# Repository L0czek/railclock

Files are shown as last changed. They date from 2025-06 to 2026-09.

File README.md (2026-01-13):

# ESP32 Mainboard (Railclock-derived)

> A general-purpose ESP32-C6 module mainboard originally created for the Railclock project and redesigned as a generic controller and motor-power board.

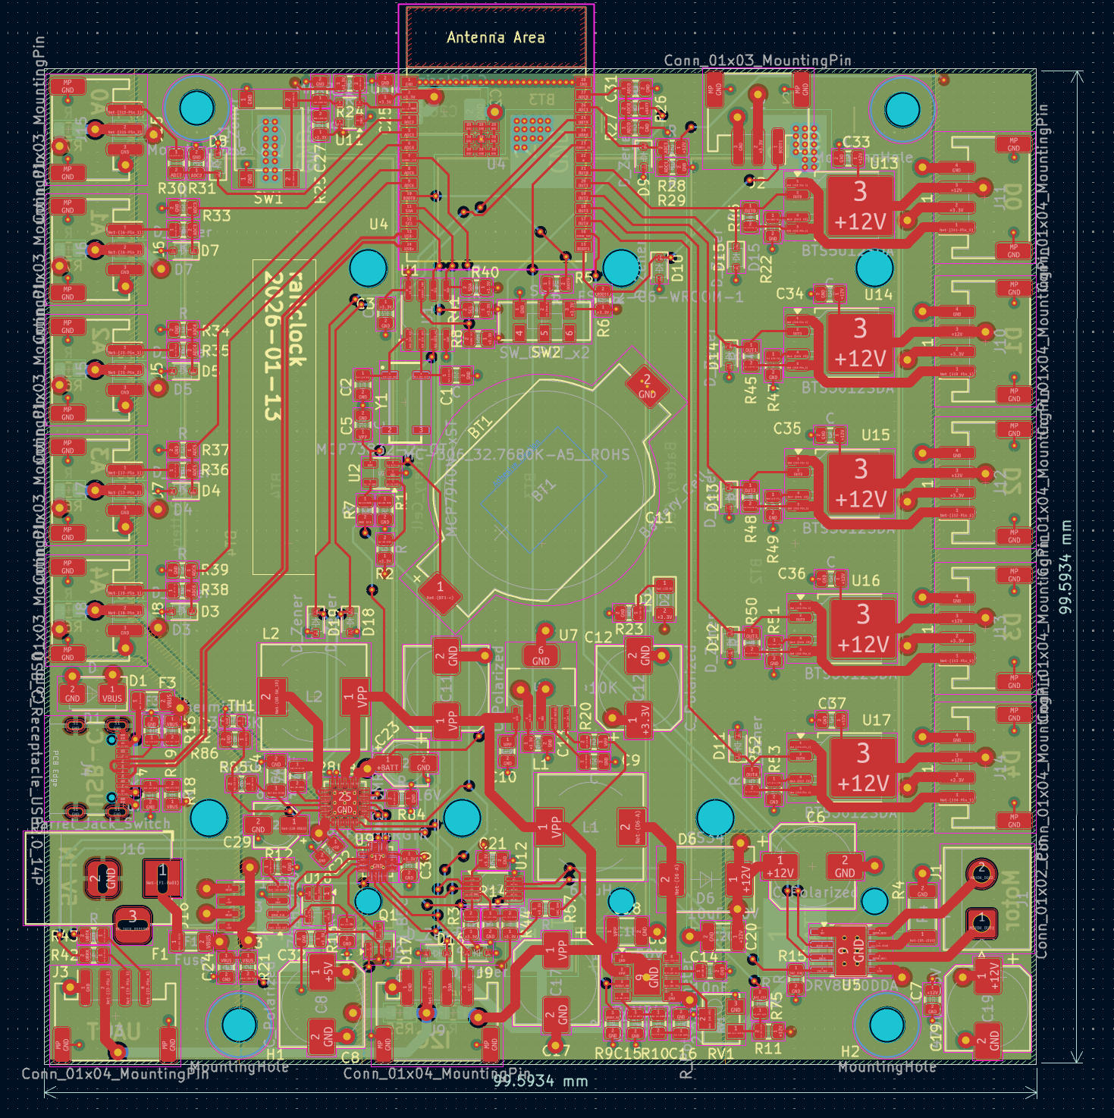
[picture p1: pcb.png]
PCB top view


This PCB exposes 11 GPIOs via JST connectors for sensors and actuators. It can run without an external 5V supply by using an on-board battery charger and a boost converter to create a 12V rail for motors and higher-power peripherals.

## Key Features

- 11 accessible GPIOs on JST connectors (5 ADC-capable ports on the left, 5 digital/drive outputs on the right).
- Left side ports: ADC-capable pins and a selectable 5V supply (powered by on-board 5V regulator/charger when available).
- Right side ports: digitally-driven output stage able to source up to 12V and ~800 mA (per port design limits depend on load and thermal conditions).
- On-board power management:
  - BQ24296M battery charger to accept battery power and produce the 5V line when no external USB is present.
  - PAM2421 boost converter to generate the 12V rail from the battery/5V bus.
- Motor driver: DRV8870 used to drive DC motors from the 12V rail.
- RTC clock MCP7940n with separate battery.

## Hardware Overview

- Connectors:
  - Left JST ports: ADC-capable pins. Expect up to 5V on these when the 5V supply is enabled — do not exceed 5V on ADC inputs.
  - Right JST ports: digital outputs with high-side/outstage to provide up to 12V for actuators.
- Power flow:
  - Primary charge/power management by the BQ24296M allows operation from a Li-ion battery without external 5V.
  - The PAM2421 boost converter takes the available rail and creates the 12V bus used by the outputs and motor driver.
- Motor driver:
  - DRV8870 drives DC motors using the 12V rail; follow the datasheet for current-limiting and heat-sinking requirements.

## Firmware

Firmware for this board is written in Rust and maintained in a separate repository: https://github.com/L0czek/esp32-mainboard

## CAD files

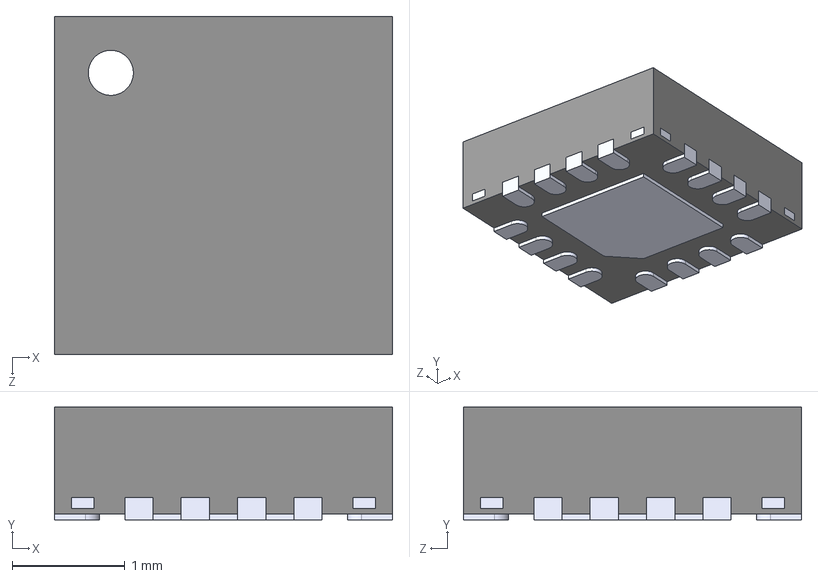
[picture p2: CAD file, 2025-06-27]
th/PCF8574RGTR.step
3.00 x 1.00 x 3.00 mm

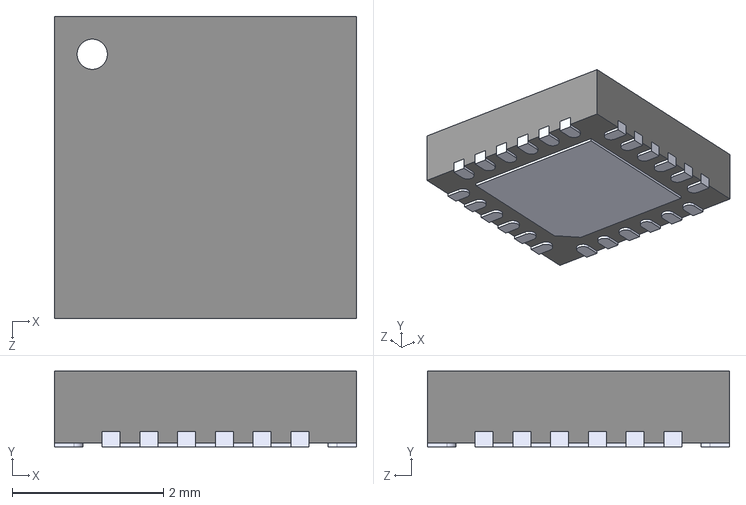
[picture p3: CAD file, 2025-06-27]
th/BQ24296MRGET.step
4.00 x 1.00 x 4.00 mm

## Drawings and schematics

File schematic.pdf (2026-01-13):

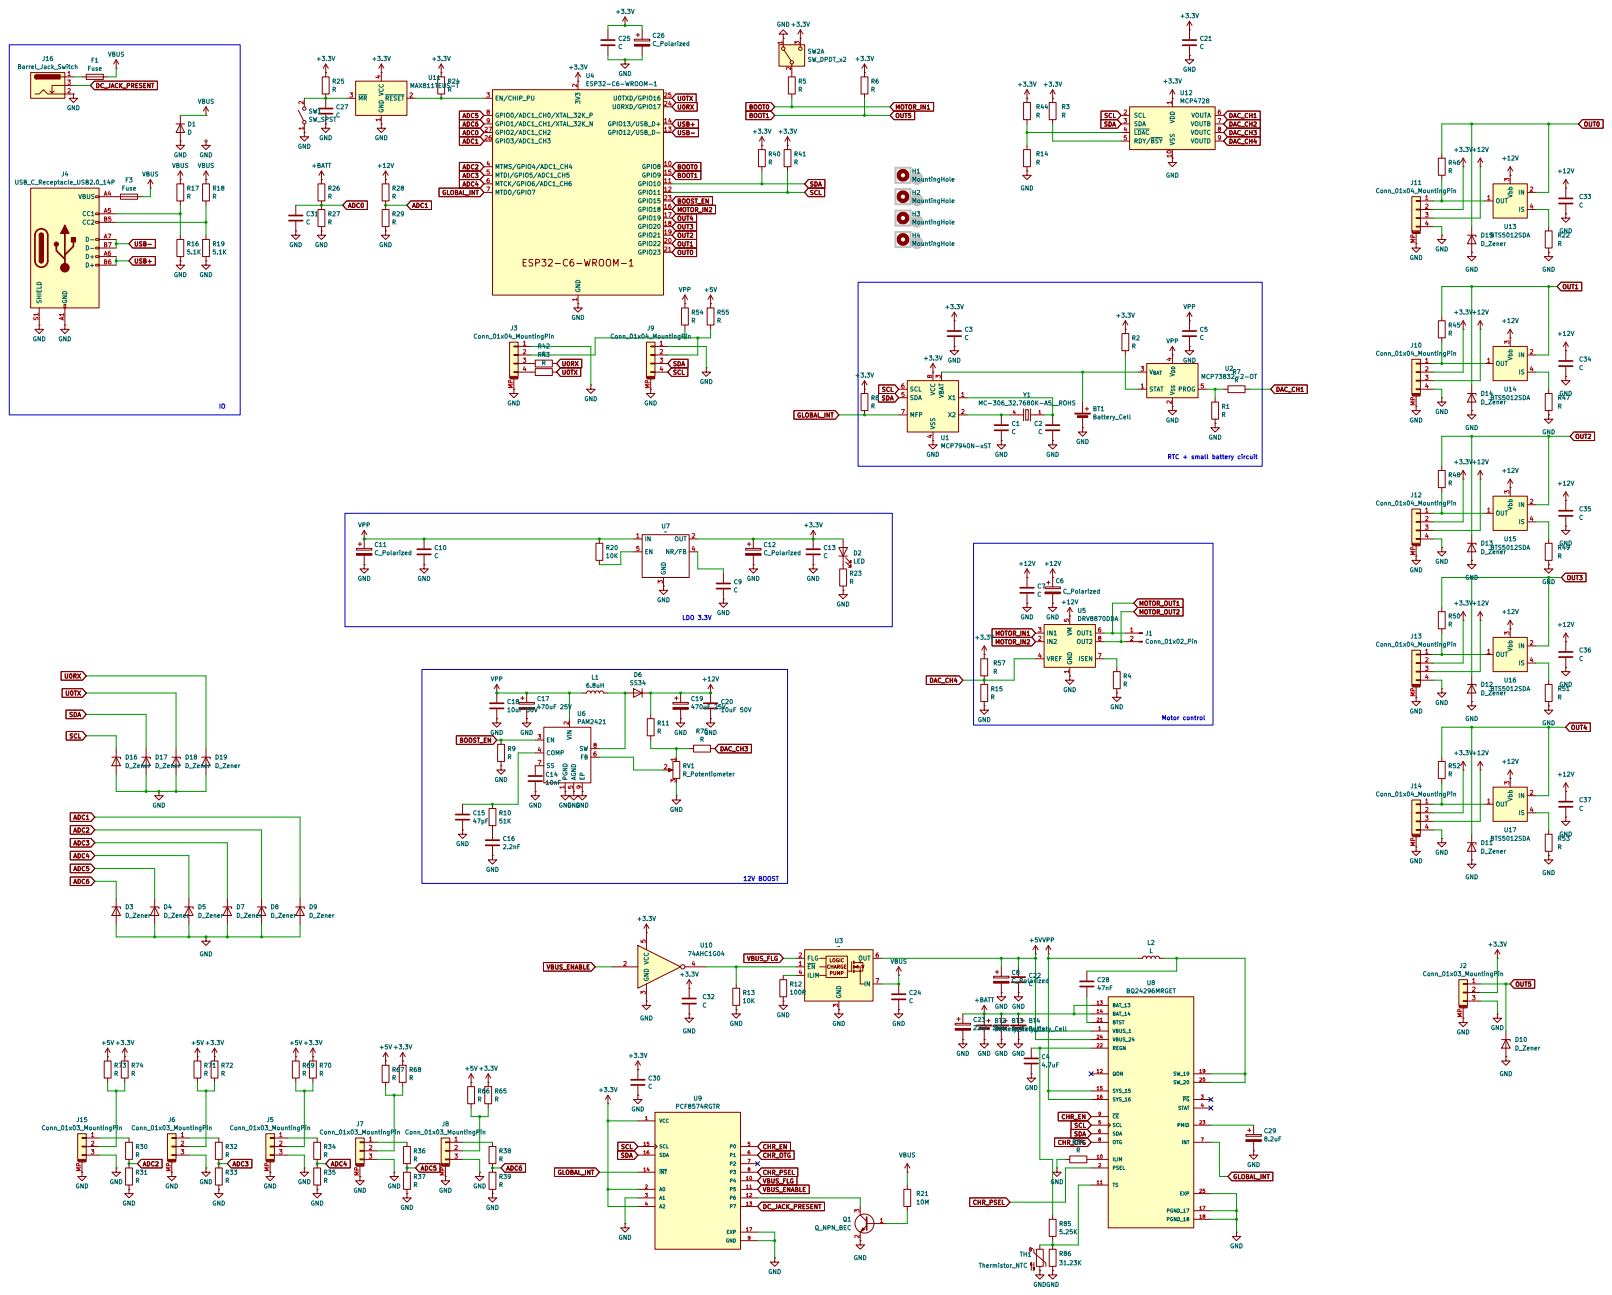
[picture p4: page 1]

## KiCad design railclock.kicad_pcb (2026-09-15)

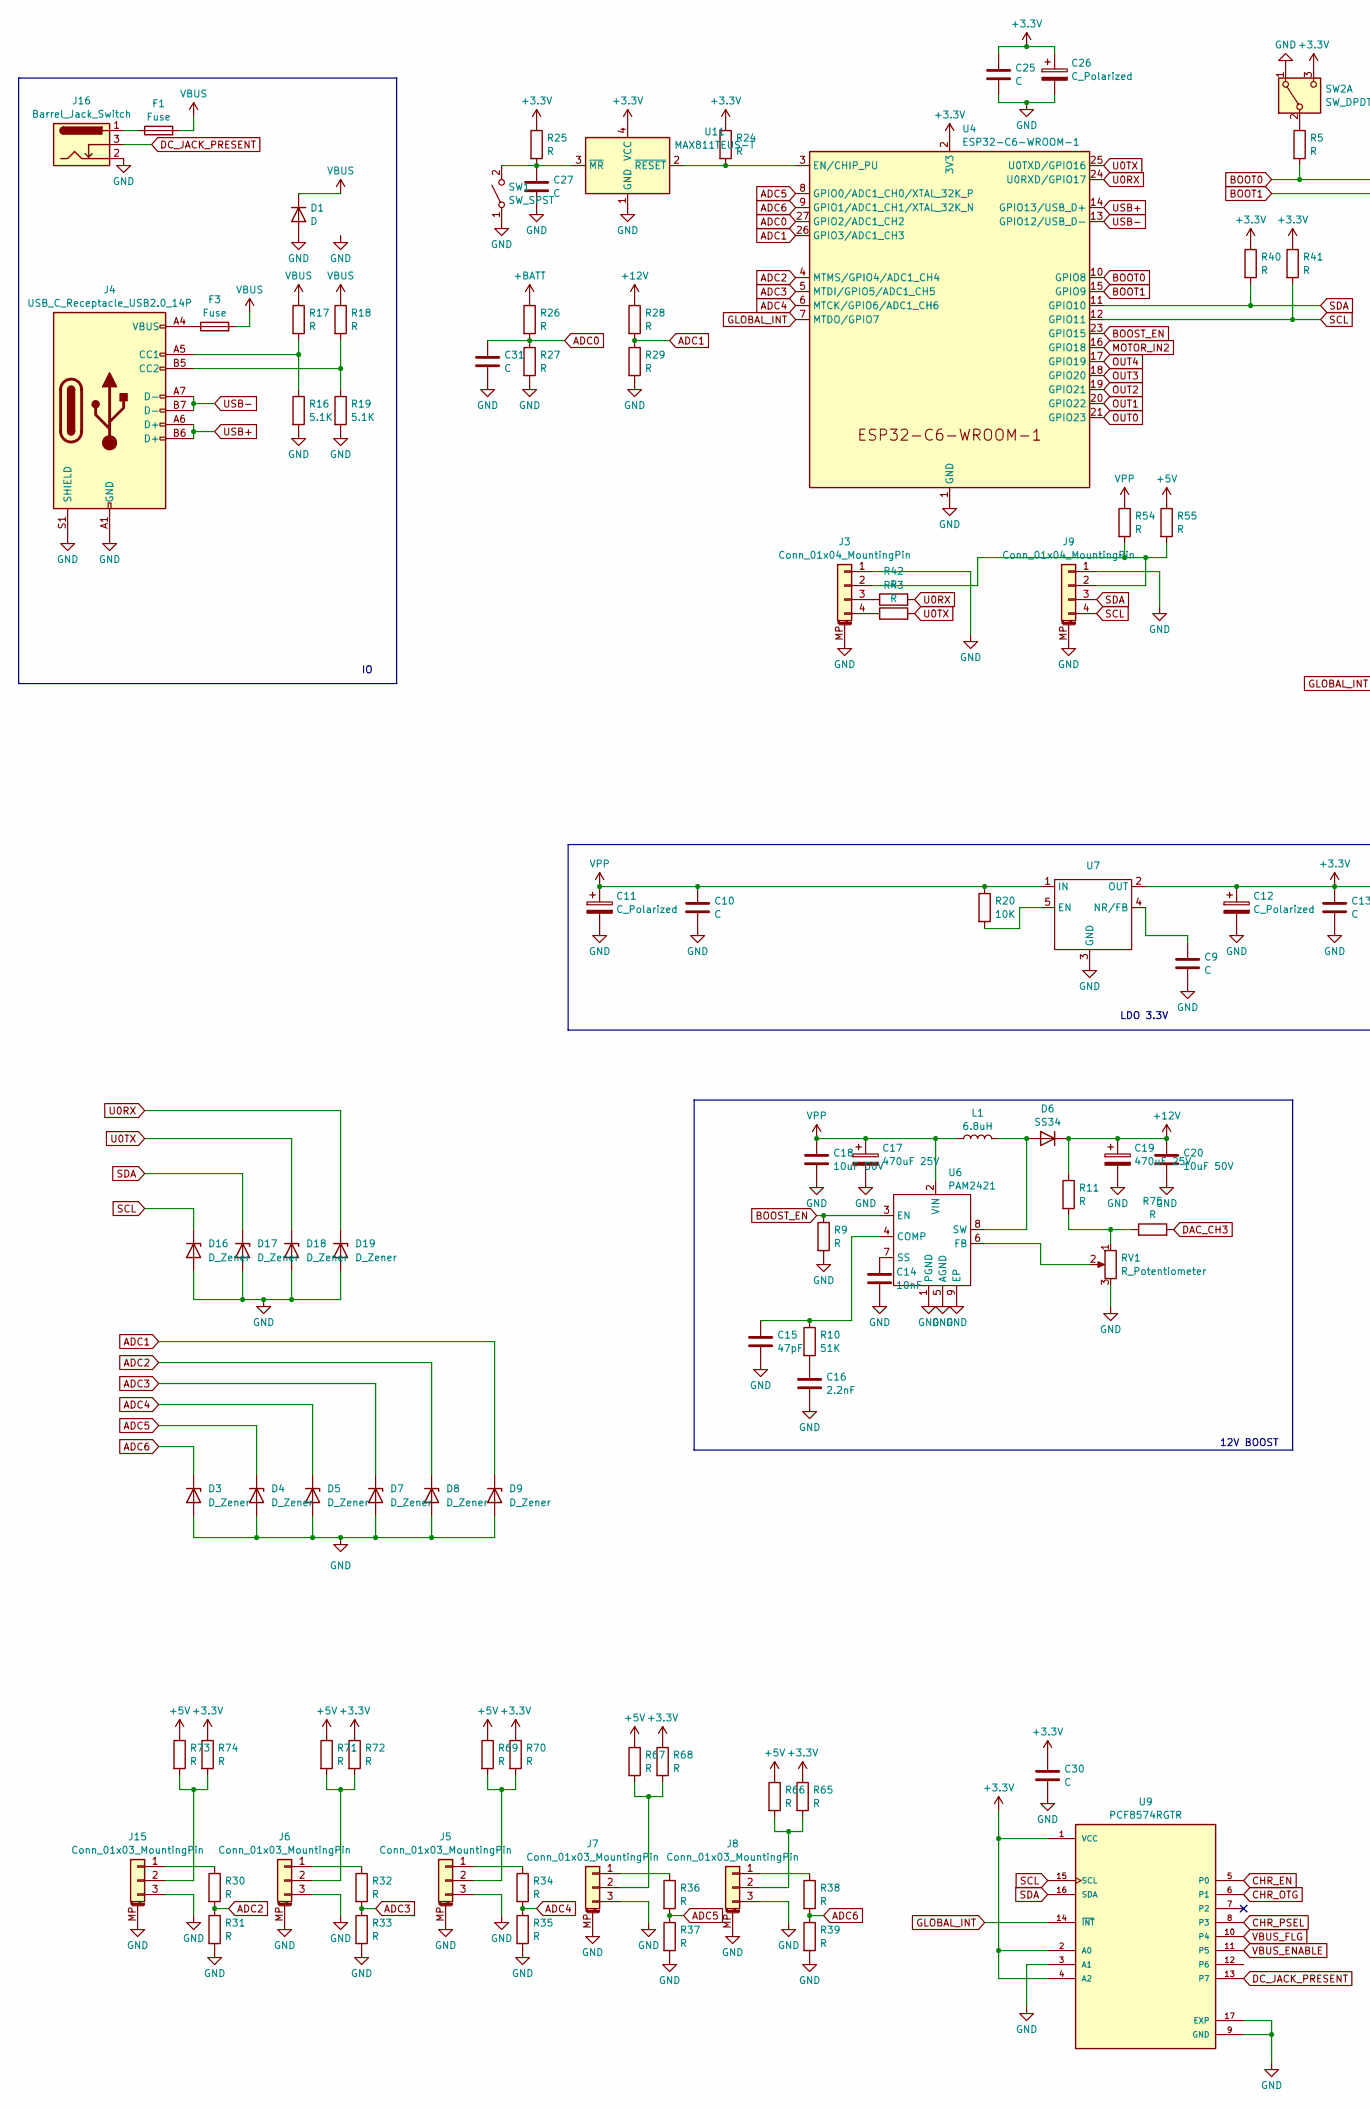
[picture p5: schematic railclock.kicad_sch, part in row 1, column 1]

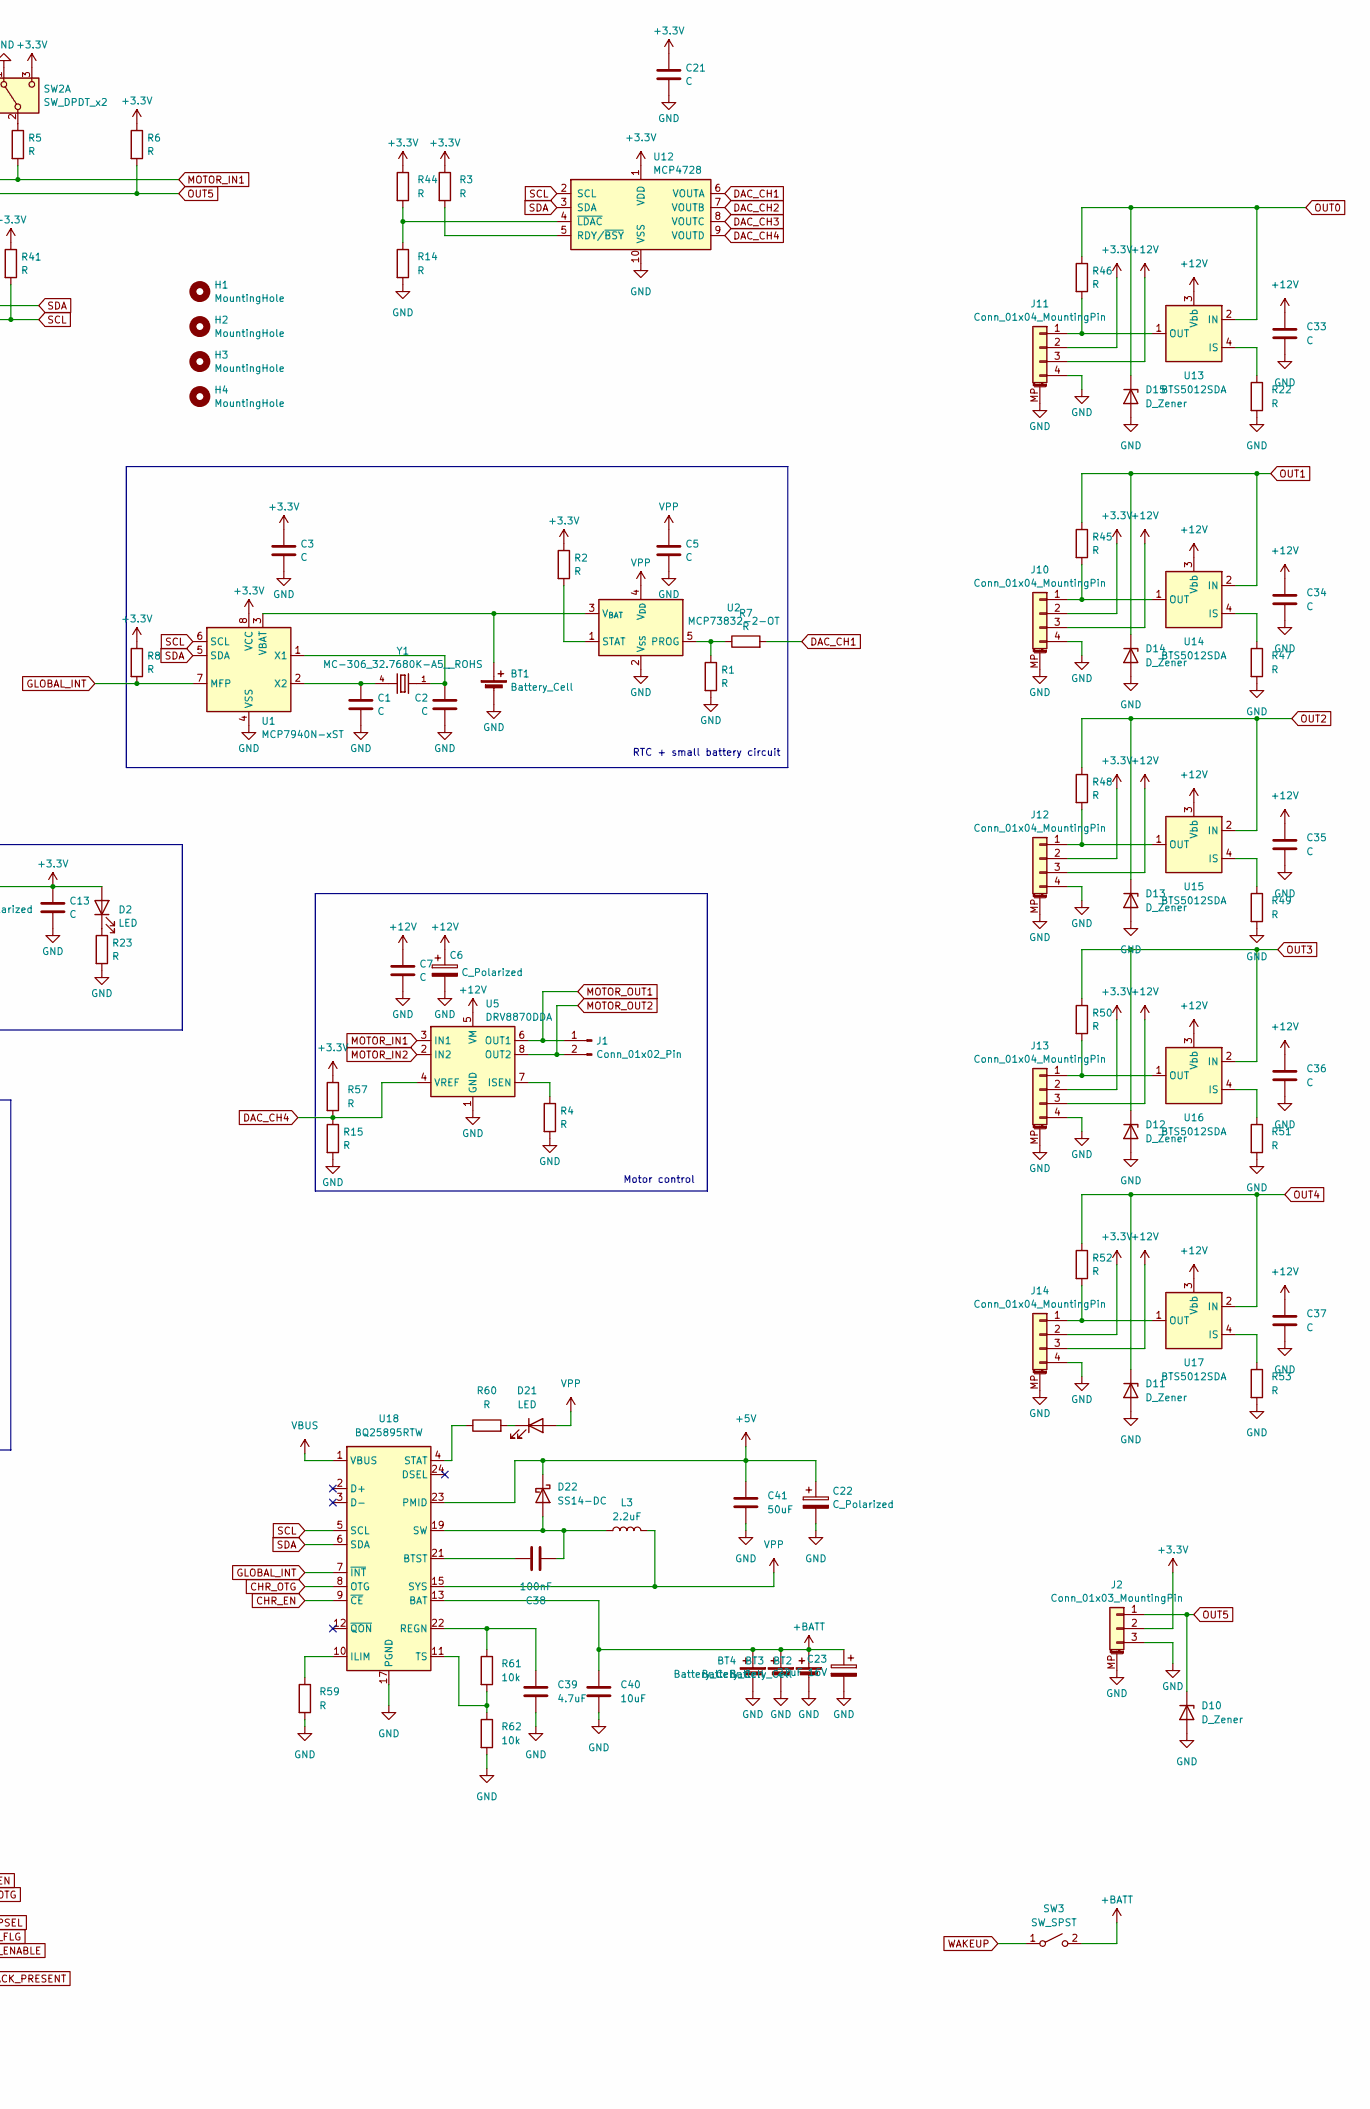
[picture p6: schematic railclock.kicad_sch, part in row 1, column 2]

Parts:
BT1: Battery_Cell; BatteryHolder_Renata_SMTU2032-LF_1x2032
BT2, BT3, BT4: Battery_Cell; BatteryHolder_Keystone_1042_1x18650
C1, C2, C3, C5, C7, C9, C10, C13, C21, C25, C27, C30, C31, C33, C34, C35, C36, C37: C; C_0805_2012Metric
C6, C11, C12, C22: C_Polarized; CP_Elec_8x10
C14: 10nF; C_0805_2012Metric
C15: 47pF; C_0805_2012Metric
C16: 2.2nF; C_0805_2012Metric
C17, C19: 470uF 25V; CP_Elec_8x10
C18, C20: 10uF 50V; C_1210_3225Metric
C23: 22uF 16V; CP_Elec_4x5.3
C26: C_Polarized; CP_EIA-7343-31_Kemet-D
C38: 100nF; C_0805_2012Metric
C39: 4.7uF; C_0805_2012Metric
C40: 10uF; C_0805_2012Metric
C41: 50uF; C_0805_2012Metric
D1: D; D_SMA
D2: LED; LED_1206_3216Metric
D3, D4, D5, D7, D8, D9, D10, D11, D12, D13, D14, D15, D16, D17, D18, D19: D_Zener; D_SOD-323
D6: SS34; D_SMC
D21: LED; LED_0805_2012Metric
D22: SS14-DC; D_SMA
F1, F3: Fuse; Fuse_1206_3216Metric
H1, H2, H3, H4: MountingHole; MountingHole_3.2mm_M3
J1: Conn_01x02_Pin; JST_NV_B02P-NV_1x02_P5.00mm_Vertical
J2, J5, J6, J7, J8, J15: Conn_01x03_MountingPin; JST_PH_S3B-PH-SM4-TB_1x03-1MP_P2.00mm_Horizontal
J3, J9, J10, J11, J12, J13, J14: Conn_01x04_MountingPin; JST_PH_S4B-PH-SM4-TB_1x04-1MP_P2.00mm_Horizontal
J4: USB_C_Receptacle_USB2.0_14P; USB_C_Receptacle_GCT_USB4105-xx-A_16P_TopMnt_Horizontal
J16: Barrel_Jack_Switch; BarrelJack_Horizontal
L1: 6.8uH; L_10.4x10.4_H4.8
L3: 2.2uF; L_Bourns_SRP1038C_10.0x10.0mm
R1, R2, R3, R5, R6, R7, R8, R9, R11, R14, R15, R17, R18, R22, R23, R24, R25, R26, R27, R28, R29, R30, R31, R32, R33, R34, R35, R36, R37, R38, R39, R40, R41, R42, R43, R44, R45, R46, R47, R48, R49, R50, R51, R52, R53, R54, R55, R57, R59, R60, R65, R66, R67, R68, R69, R70, R71, R72, R73, R74, R75: R; R_0805_2012Metric
R4: R; R_2010_5025Metric
R10: 51K; R_0805_2012Metric
R16, R19: 5.1K; R_0805_2012Metric
R20: 10K; R_0805_2012Metric
R61, R62: 10k; R_0805_2012Metric
RV1: R_Potentiometer; Potentiometer_Bourns_3214W_Vertical
SW1: SW_SPST; SW_SPST_B3S-1000
SW2: SW_DPDT_x2; SW_DPDT_CK_JS202011JCQN
SW3: SW_SPST; Panasonic_EVQPUL_EVQPUC
U1: MCP7940N-xST; SOIC-8_3.9x4.9mm_P1.27mm
U2: MCP73832-2-OT; SOT-23-5
U4: ESP32-C6-WROOM-1
U5: DRV8870DDA; Texas_HTSOP-8-1EP_3.9x4.9mm_P1.27mm_EP2.95x4.9mm_Mask2.4x3.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
U6: PAM2421; Diodes_SO-8EP
U7: SOT-223-6
U9: PCF8574RGTR; QFN50P300X300X100-17N; PARTREV J; DigiKey_Part_Number 296-21238-2-ND
U11: MAX811TEUS-T; SOT-143
U12: MCP4728; MSOP-10_3x3mm_P0.5mm
U13, U14, U15, U16, U17: BTS5012SDA; TO-252-4
U18: BQ25895RTW; Texas_RTW_WQFN-24-1EP_4x4mm_P0.5mm_EP2.7x2.7mm_ThermalVias
Y1: MC-306_32.7680K-A5__ROHS; OSCL550P800X320X254-4N

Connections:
+3.3V: C3.1, C12.1, C13.1, C21.1, C25.1, C26.1, C30.1, D2.2 (A), J2.2, J10.2, J11.2, J12.2, J13.2, J14.2, R2.1, R3.1, R6.1, R8.1, R24.1, R25.1, R40.1, R41.1, R44.1, R57.1, R65.1, R68.1, R70.1, R72.1, R74.1, SW2.3 (C), U1.8 (VCC), U4.2 (3V3), U7.2 (OUT), U9.1 (VCC), U9.2 (A0), U9.4 (A2), U11.4 (VCC), U12.1 (VDD)
+5V: C22.1, C41.1, D22.1 (K), R55.1, R66.1, R67.1, R69.1, R71.1, R73.1, U18.23 (PMID)
+12V: C6.1, C7.1, C19.1, C20.1, C33.1, C34.1, C35.1, C36.1, C37.1, D6.1 (K), J10.3, J11.3, J12.3, J13.3, J14.3, R11.1, R28.1, U5.5 (VM), U13.3 (Vbb), U14.3 (Vbb), U15.3 (Vbb), U16.3 (Vbb), U17.3 (Vbb)
+BATT: BT2.1 (+), BT3.1 (+), BT4.1 (+), C23.1, C40.1, R26.1, SW3.2 (B), U18.13 (BAT), U18.14 (BAT)
ADC0: C31.1, R26.2, R27.1, U4.27 (GPIO2/ADC1_CH2)
ADC1: D9.1 (K), R28.2, R29.1, U4.26 (GPIO3/ADC1_CH3)
ADC2: D8.1 (K), R30.2, R31.1, U4.4 (MTMS/GPIO4/ADC1_CH4)
ADC3: D7.1 (K), R32.2, R33.1, U4.5 (MTDI/GPIO5/ADC1_CH5)
ADC4: D5.1 (K), R34.2, R35.1, U4.6 (MTCK/GPIO6/ADC1_CH6)
ADC5: D4.1 (K), R36.2, R37.1, U4.8 (GPIO0/ADC1_CH0/XTAL_32K_P)
ADC6: D3.1 (K), R38.2, R39.1, U4.9 (GPIO1/ADC1_CH1/XTAL_32K_N)
BOOST_EN: R9.1, U4.23 (GPIO15), U6.3 (EN)
BOOT0: R5.2, U4.10 (GPIO8), U5.3 (IN1)
BOOT1: D10.1 (K), J2.1, R6.2, U4.15 (GPIO9)
CHR_EN: U9.5 (P0), U18.9 (~CE)
CHR_OTG: U9.6 (P1), U18.8 (OTG)
CHR_PSEL: U9.8 (P3)
DAC_CH1: R7.2, U12.6 (VOUTA)
DAC_CH2: U12.7 (VOUTB)
DAC_CH3: R75.2, U12.8 (VOUTC)
DAC_CH4: R15.1, R57.2, U5.4 (VREF), U12.9 (VOUTD)
DC_JACK_PRESENT: J16.3, U9.13 (P7)
GLOBAL_INT: R8.2, U1.7 (MFP), U4.7 (MTDO/GPIO7), U9.14 (~INT), U18.7 (~INT)
GND: BT1.2 (-), BT2.2 (-), BT3.2 (-), BT4.2 (-), C1.2, C2.2, C3.2, C5.2, C6.2, C7.2, C9.2, C10.2, C11.2, C12.2, C13.2, C14.2, C15.2, C16.2, C17.2, C18.2, C19.2, C20.2, C21.2, C22.2, C23.2, C25.2, C26.2, C27.2, C30.2, C31.2, C33.2, C34.2, C35.2, C36.2, C37.2, C39.2, C40.2, C41.2, D1.2 (A), D3.2 (A), D4.2 (A), D5.2 (A), D7.2 (A), D8.2 (A), D9.2 (A), D10.2 (A), D11.2 (A), D12.2 (A), D13.2 (A), D14.2 (A), D15.2 (A), D16.2 (A), D17.2 (A), D18.2 (A), D19.2 (A), J2.3, J2.MP (MountPin), J3.1, J3.MP (MountPin), J4.A1 (GND), J4.A12 (GND), J4.B1 (GND), J4.B12 (GND), J4.S1 (SHIELD), J5.3, J5.MP (MountPin), J6.3, J6.MP (MountPin), J7.3, J7.MP (MountPin), J8.3, J8.MP (MountPin), J9.1, J9.MP (MountPin), J10.4, J10.MP (MountPin), J11.4, J11.MP (MountPin), J12.4, J12.MP (MountPin), J13.4, J13.MP (MountPin), J14.4, J14.MP (MountPin), J15.3, J15.MP (MountPin), J16.2, R1.2, R4.2, R9.2, R14.2, R15.2, R16.2, R19.2, R22.2, R23.2, R27.2, R29.2, R31.2, R33.2, R35.2, R37.2, R39.2, R47.2, R49.2, R51.2, R53.2, R59.2, R62.2, RV1.3, SW1.1 (A), SW2.1 (A), U1.4 (VSS), U2.2 (V_{SS}), U4.1 (GND), U4.28 (GND), U4.29 (GND), U5.1 (GND), U5.9 (GND), U6.1 (PGND), U6.5 (AGND), U6.9 (EP), U7.3 (GND), U7.6 (GND), U9.3 (A1), U9.9 (GND), U9.17 (EXP), U11.1 (GND), U12.10 (VSS), U18.17 (PGND), U18.18 (PGND), U18.25 (PGND)
MOTOR_IN2: U4.16 (GPIO18), U5.2 (IN2)
MOTOR_OUT1: J1.1, U5.6 (OUT1)
MOTOR_OUT2: J1.2, U5.8 (OUT2)
unnamed: BT1.1 (+), U1.3 (VBAT), U2.3 (V_{BAT})
unnamed: C16.1, R10.2
unnamed: D2.1 (K), R23.1
unnamed: D6.2 (A), L1.2, U6.8 (SW)
unnamed: D21.1 (K), R60.2
unnamed: C38.1, D22.2 (A), L3.1, U18.19 (SW), U18.20 (SW)
unnamed: F1.1, J16.1
unnamed: F3.1, J4.A4 (VBUS), J4.A9 (VBUS), J4.B4 (VBUS), J4.B9 (VBUS)
unnamed: J3.2, J9.2, R54.2, R55.2
unnamed: J3.3, R42.1
unnamed: J3.4, R43.1
unnamed: J4.A5 (CC1), R16.1, R17.2
unnamed: J4.B5 (CC2), R18.2, R19.1
unnamed: J5.1, R34.1
unnamed: J5.2, R69.2, R70.2
unnamed: J6.1, R32.1
unnamed: J6.2, R71.2, R72.2
unnamed: J7.1, R36.1
unnamed: J7.2, R67.2, R68.2
unnamed: J8.1, R38.1
unnamed: J8.2, R65.2, R66.2
unnamed: J10.1, R45.2, U14.1 (OUT), U14.5 (OUT)
unnamed: J11.1, R46.2, U13.1 (OUT), U13.5 (OUT)
unnamed: J12.1, R48.2, U15.1 (OUT), U15.5 (OUT)
unnamed: J13.1, R50.2, U16.1 (OUT), U16.5 (OUT)
unnamed: J14.1, R52.2, U17.1 (OUT), U17.5 (OUT)
unnamed: J15.1, R30.1
unnamed: J15.2, R73.2, R74.2
unnamed: R11.2, R75.1, RV1.1
unnamed: C27.1, R25.2, SW1.2 (B), U11.3 (~MR)
unnamed: R5.1, SW2.2 (B)
unnamed: C2.1, U1.1 (X1), Y1.1
unnamed: C1.1, U1.2 (X2), Y1.4
unnamed: R1.1, R7.1, U2.5 (PROG)
unnamed: R2.2, U2.1 (STAT)
unnamed: R4.1, U5.7 (ISEN)
unnamed: C15.1, R10.1, U6.4 (COMP)
unnamed: RV1.2, U6.6 (FB)
unnamed: C14.1, U6.7 (SS)
unnamed: R20.2, U7.5 (EN)
unnamed: C9.1, U7.4 (NR/FB)
unnamed: R24.2, U4.3 (EN/CHIP_PU), U11.2 (~RESET)
unnamed: R3.2, U12.5 (RDY/~BSY)
unnamed: R14.1, R44.2, U12.4 (~LDAC)
unnamed: R22.1, U13.4 (IS)
unnamed: R47.1, U14.4 (IS)
unnamed: R49.1, U15.4 (IS)
unnamed: R51.1, U16.4 (IS)
unnamed: R53.1, U17.4 (IS)
unnamed: C38.2, U18.21 (BTST)
unnamed: R59.1, U18.10 (ILIM)
unnamed: C39.1, R61.1, U18.22 (REGN)
unnamed: R60.1, U18.4 (STAT)
unnamed: R61.2, R62.1, U18.11 (TS)
OUT0: D15.1 (K), R46.1, U4.21 (GPIO23), U13.2 (IN)
OUT1: D14.1 (K), R45.1, U4.20 (GPIO22), U14.2 (IN)
OUT2: D13.1 (K), R48.1, U4.19 (GPIO21), U15.2 (IN)
OUT3: D12.1 (K), R50.1, U4.18 (GPIO20), U16.2 (IN)
OUT4: D11.1 (K), R52.1, U4.17 (GPIO19), U17.2 (IN)
SCL: D16.1 (K), J9.4, R41.2, U1.6 (SCL), U4.12 (GPIO11), U9.15 (SCL), U12.2 (SCL), U18.5 (SCL)
SDA: D17.1 (K), J9.3, R40.2, U1.5 (SDA), U4.11 (GPIO10), U9.16 (SDA), U12.3 (SDA), U18.6 (SDA)
U0RX: D19.1 (K), R42.2, U4.24 (U0RXD/GPIO17)
U0TX: D18.1 (K), R43.2, U4.25 (U0TXD/GPIO16)
USB+: J4.A6 (D+), J4.B6 (D+), U4.14 (GPIO13/USB_D+)
USB-: J4.A7 (D-), J4.B7 (D-), U4.13 (GPIO12/USB_D-)
VBUS: D1.1 (K), F1.2, F3.2, R17.1, R18.1, U18.1 (VBUS)
VBUS_ENABLE: U9.11 (P5)
VBUS_FLG: U9.10 (P4)
VPP: C5.1, C10.1, C11.1, C17.1, C18.1, D21.2 (A), L1.1, L3.2, R20.1, R54.1, U2.4 (V_{DD}), U6.2 (VIN), U7.1 (IN), U18.15 (SYS), U18.16 (SYS)
WAKEUP: SW3.1 (A)

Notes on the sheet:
Motor control
12V BOOST
LDO 3.3V
RTC + small battery circuit

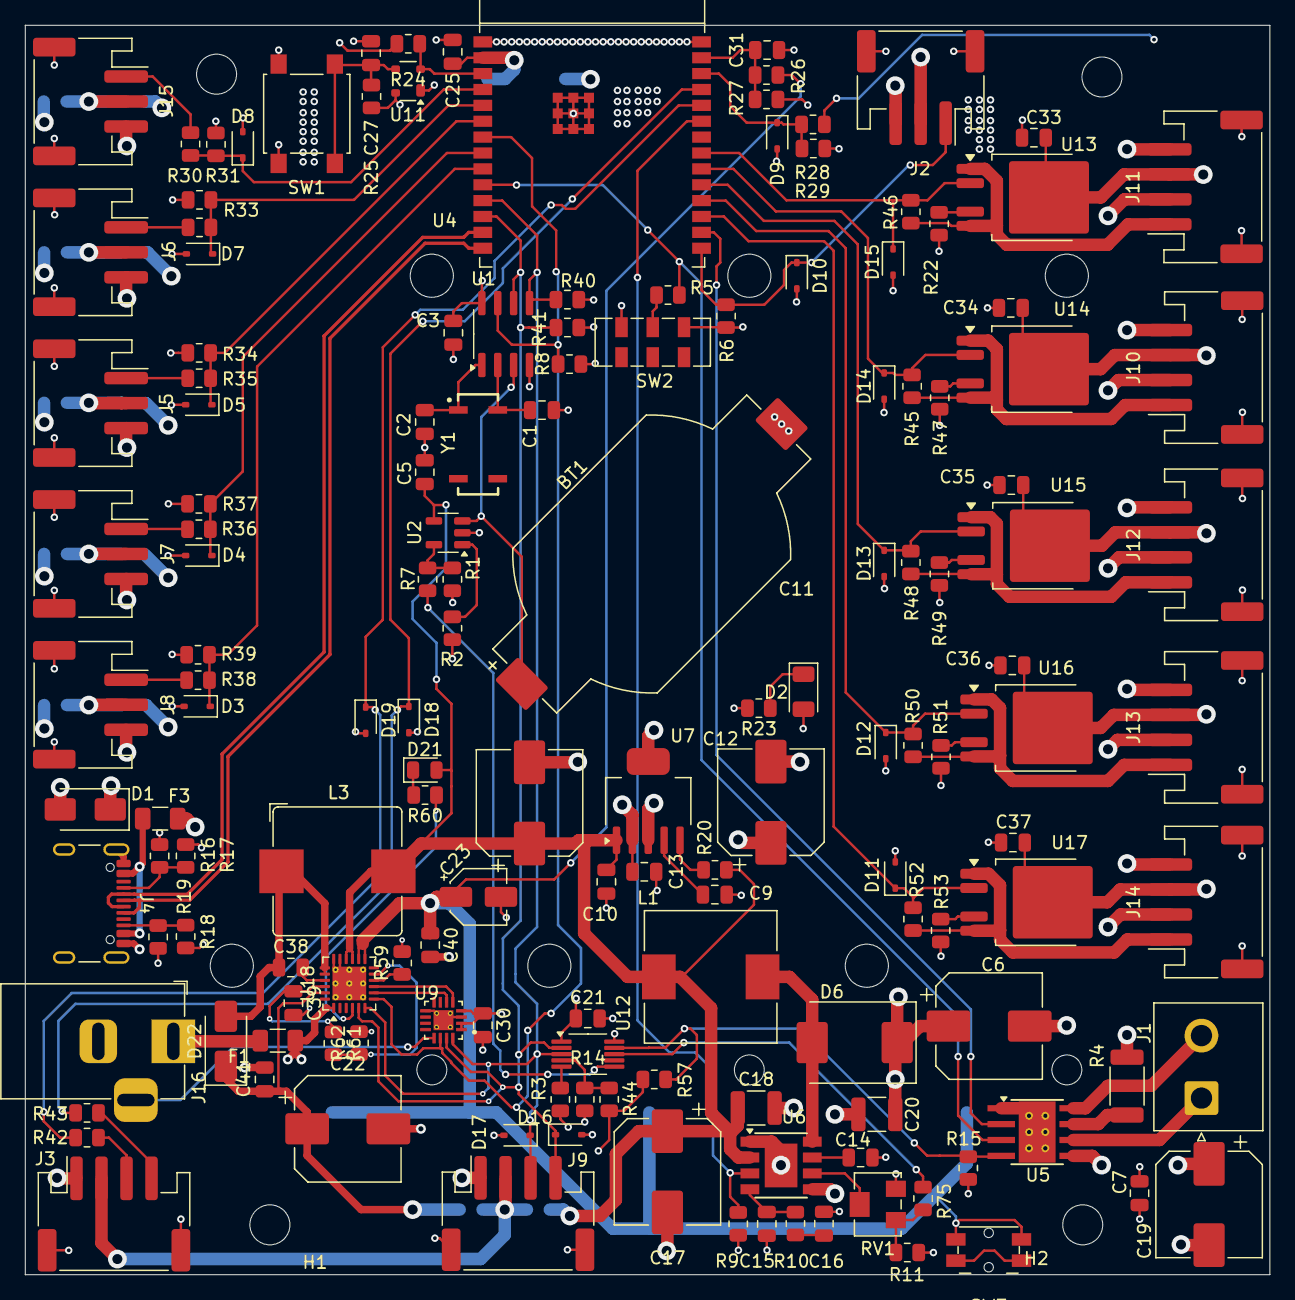
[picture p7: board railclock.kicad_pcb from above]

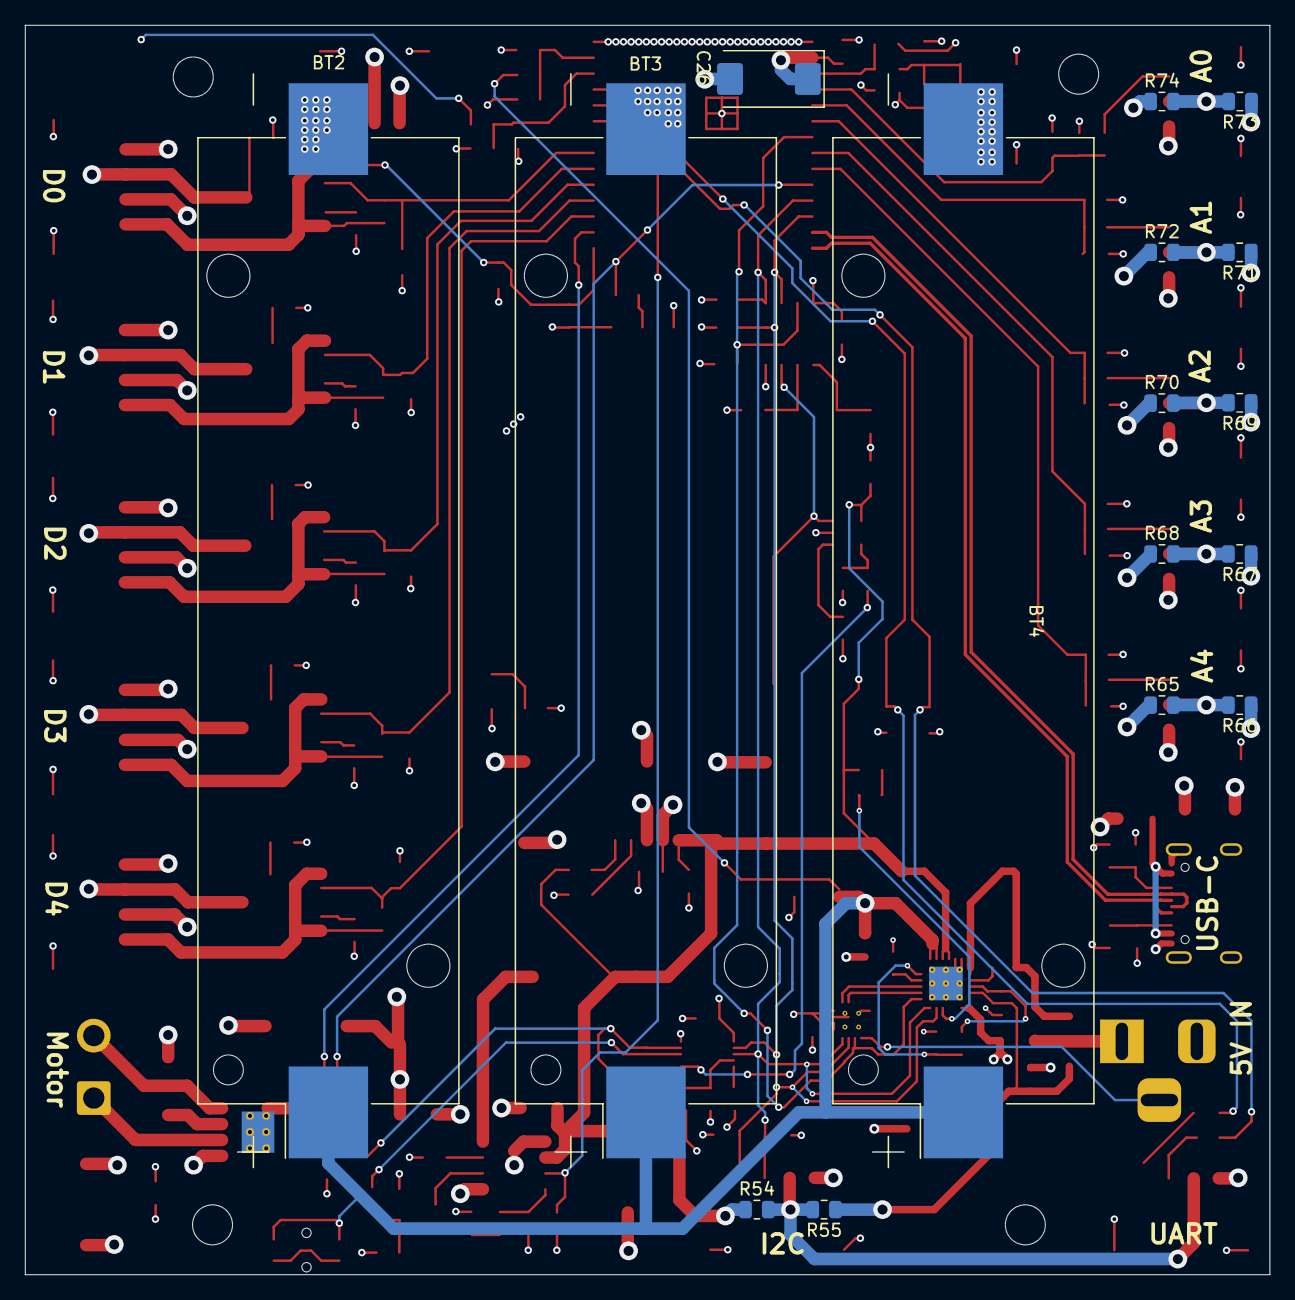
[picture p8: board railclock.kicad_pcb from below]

Board: 4 copper layers, 99.6 x 99.9 mm, 172 parts (16 on the bottom side), 92 nets.

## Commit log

2025-06-27 Add railclock pcb
    [BQ24296MRGET.step, PCF8574RGTR.step, railclock.kicad_pcb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]
2025-06-29 Fix issues with first version
    [railclock.kicad_pcb, railclock.kicad_sch]
2025-07-01 Add option to choose which volatage is avaialble on the I2C connector
    [railclock.kicad_pcb, railclock.kicad_sch]
2025-09-08 Update board, rewire digital connections
    [railclock.kicad_pcb, railclock.kicad_sch]
2025-09-09 Add transils to A-D pins, fix vbus detection
    [railclock.kicad_sch]
2025-09-10 Add transils fix vbus detection
    [railclock.kicad_pcb, railclock.kicad_sch]
2025-09-13 Replace UART connector
    [railclock.kicad_pcb, railclock.kicad_sch]
2025-10-07 Fix foorptints references
    [railclock.kicad_pcb]
2025-10-09 Add element values and some fixes
    [railclock.kicad_sch]
2025-10-10 Reroute to 4 layer pcb
    [railclock.kicad_pcb, railclock.kicad_sch]
2025-10-16 Rework to new kanapka
    [railclock.kicad_pcb]
2025-11-30 Add R21 value
    [railclock.kicad_sch]
2026-04-19 Fix VBUS detection and add wakeup button
    [railclock.kicad_pcb, railclock.kicad_sch]
2026-09-15 Change charger
    [railclock.kicad_pcb, railclock.kicad_sch]
